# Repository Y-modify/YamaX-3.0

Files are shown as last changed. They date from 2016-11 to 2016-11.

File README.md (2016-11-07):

# YamaX 3.0

This is the software of humanoid robot named "YamaX 3.0"
The humanoid uses the original board with ESP8266.
This repository contains 3D Models, EAGLE files, and Arduino sketch.

Detailed information about this robot can be found in the following page: 

- [Y-modify](http://www.y-modify.org)
- [Y-modify Blog](http://blog.y-modify.org)

## Directory Structure

```
.
├── Designs
│   ├── AXBoard
│   │   ├── AX-03r	#EAGLE PCB file
│   │   └── Legacy	#Legacy Board (AX-03)
│   └── Model	#3D model of YamaX
├── Docs	#Document about the history of YamaX
└── Firmware
    └── AXBoard
        ├── AXTester	#Testing Program
        └── MCore	#Main Program
```

## Licence

These files are released under MIT Licence.
Please see `LICENCE`.

## Contact

You can comment on [our blog](http://blog.y-modify.org), or send e-mail to [info@y-modify.org](mailto:info@y-modify.org).

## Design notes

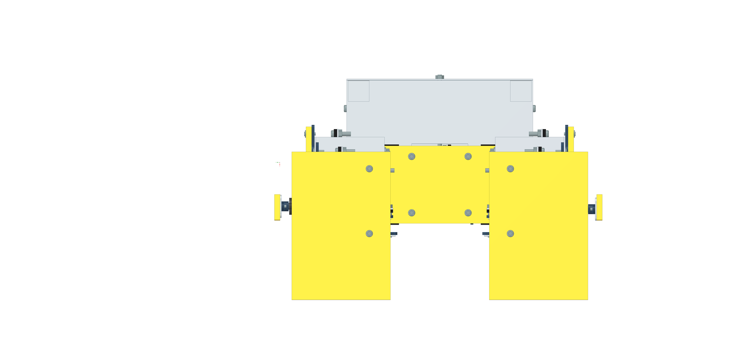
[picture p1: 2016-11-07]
Designs/Model/picts/解像度低め/YamaX3.0_redesigned_下.png

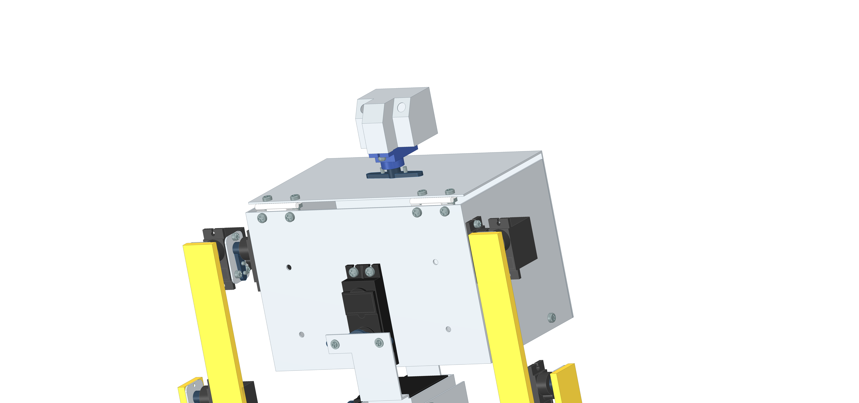
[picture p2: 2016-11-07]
Designs/Model/picts/YamaX3.0_redesigned_上半身.png

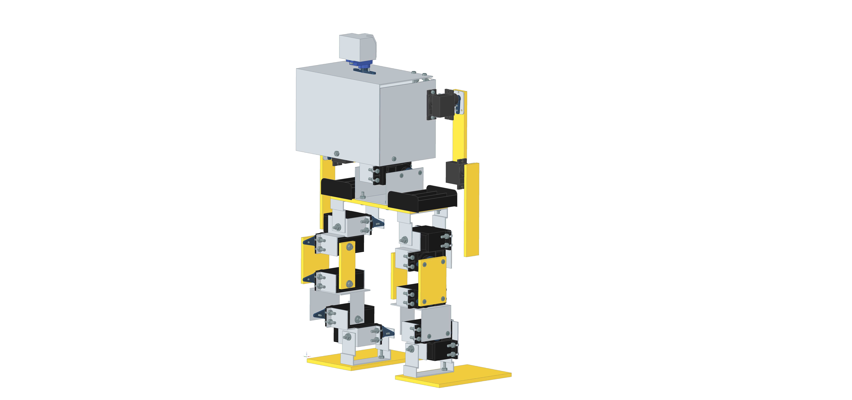
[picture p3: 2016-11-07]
Designs/Model/picts/YamaX3.0_redesigned_右後ろ.png

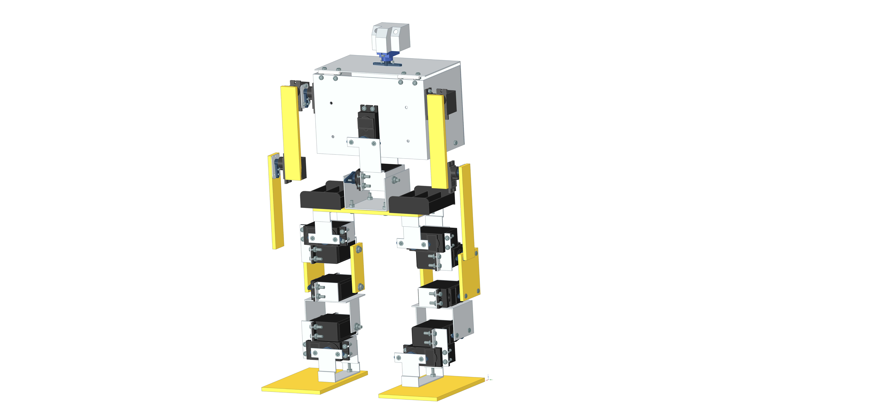
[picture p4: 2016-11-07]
Designs/Model/picts/YamaX3.0_redesigned_左前.png

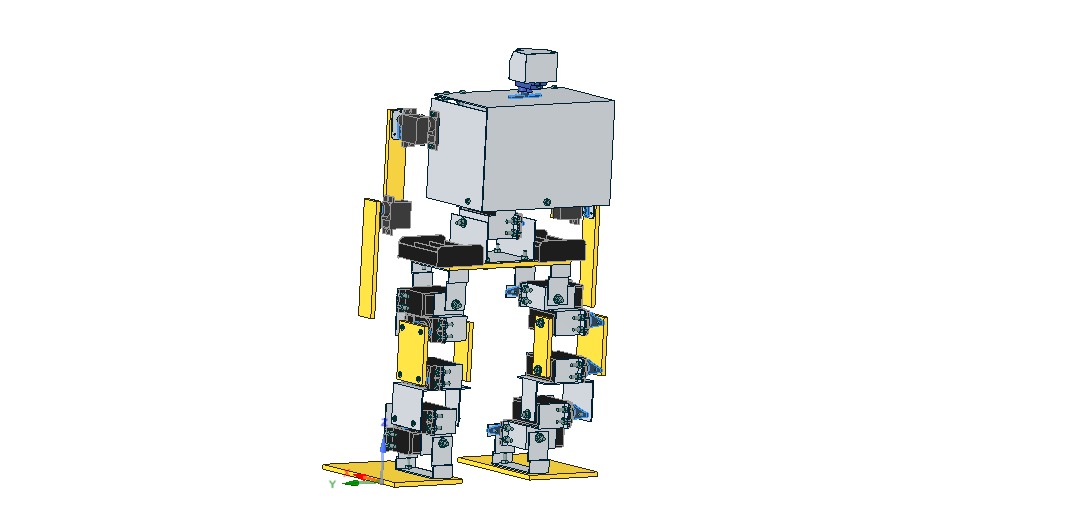
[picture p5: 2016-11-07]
Designs/Model/picts/解像度低め/5000/YamaX3.0_redesigned_左後ろ.jpg

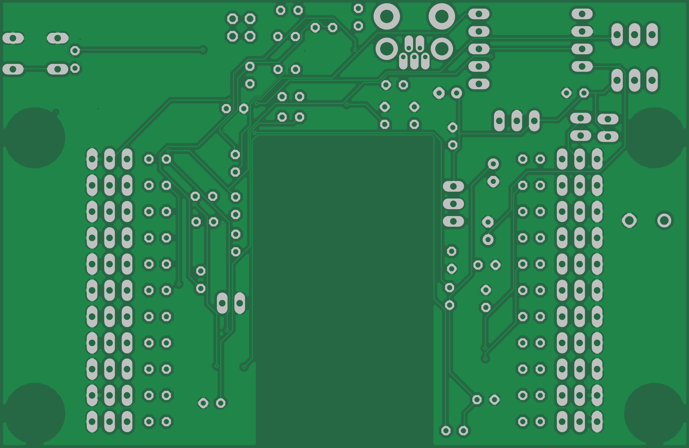
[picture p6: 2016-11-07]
Designs/AXBoard/AX-03r/Models/pcb/eagleUp_AX-03r_bottom_board.png

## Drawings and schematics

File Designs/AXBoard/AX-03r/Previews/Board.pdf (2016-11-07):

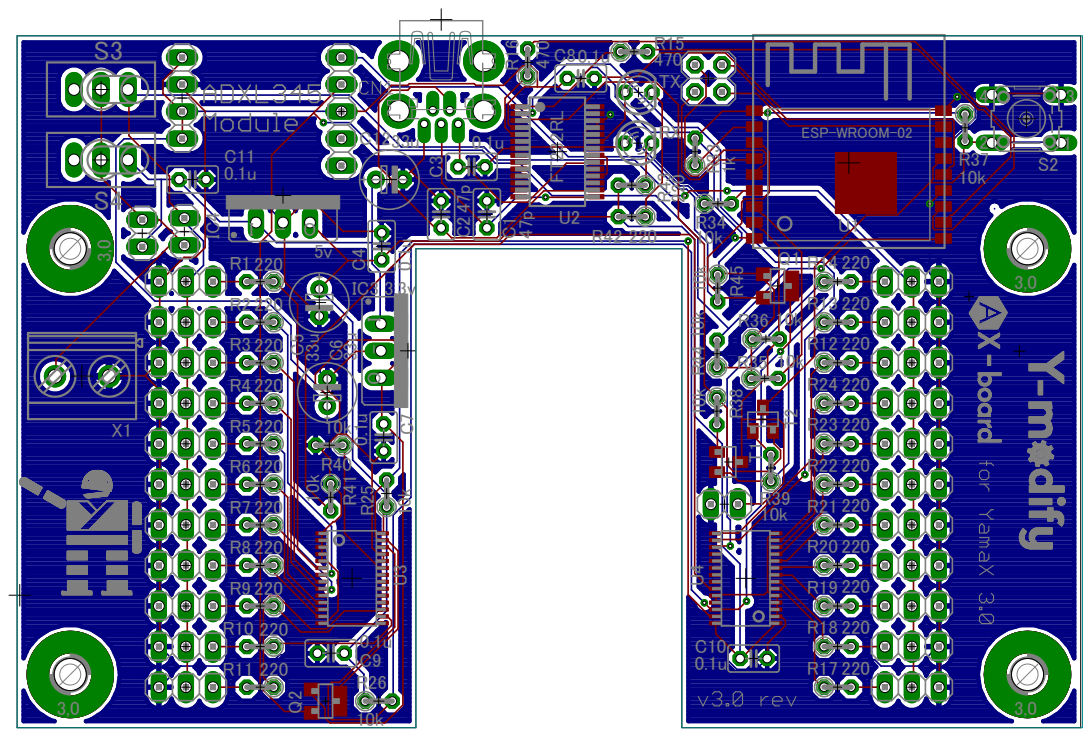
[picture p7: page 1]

- I O 2 1 4 3 I - O C1C2 C3 C4 C5 C6 C7 U1 U2 IC3 R1 R10 R11 R12 R13 R14 R17 R18 R19 R2 R20 R21 R22 R3 R33 R34 R35 R36 R37 R38 R39 R4 R40 R41 R42 R43 R44 R45 R5R6R7R8R9 RX S2 S3S4 T1 T2 TX U3U4 X1 R23 R24 R15 R16 C8 C9 C10 C11 C12 IC4 Q1 Q2 R25 R26 47p47p 0.1u 0.1u 33u 33u 0.1u ESP-WROOM-02 FT232RL 3.3v 220 220 220 220 220 220 220 220 220 220 220 220 220 220 1k 10k 10k 10k 10k 10k 10k 220 10k 10k 220 220 10k 10k 220 220 220 220 220 220 220 4470 70 0.1u 0.1u 0.1u 0.1u 33u 5v 10k 10k 3,0 3,0 3,0 3,0

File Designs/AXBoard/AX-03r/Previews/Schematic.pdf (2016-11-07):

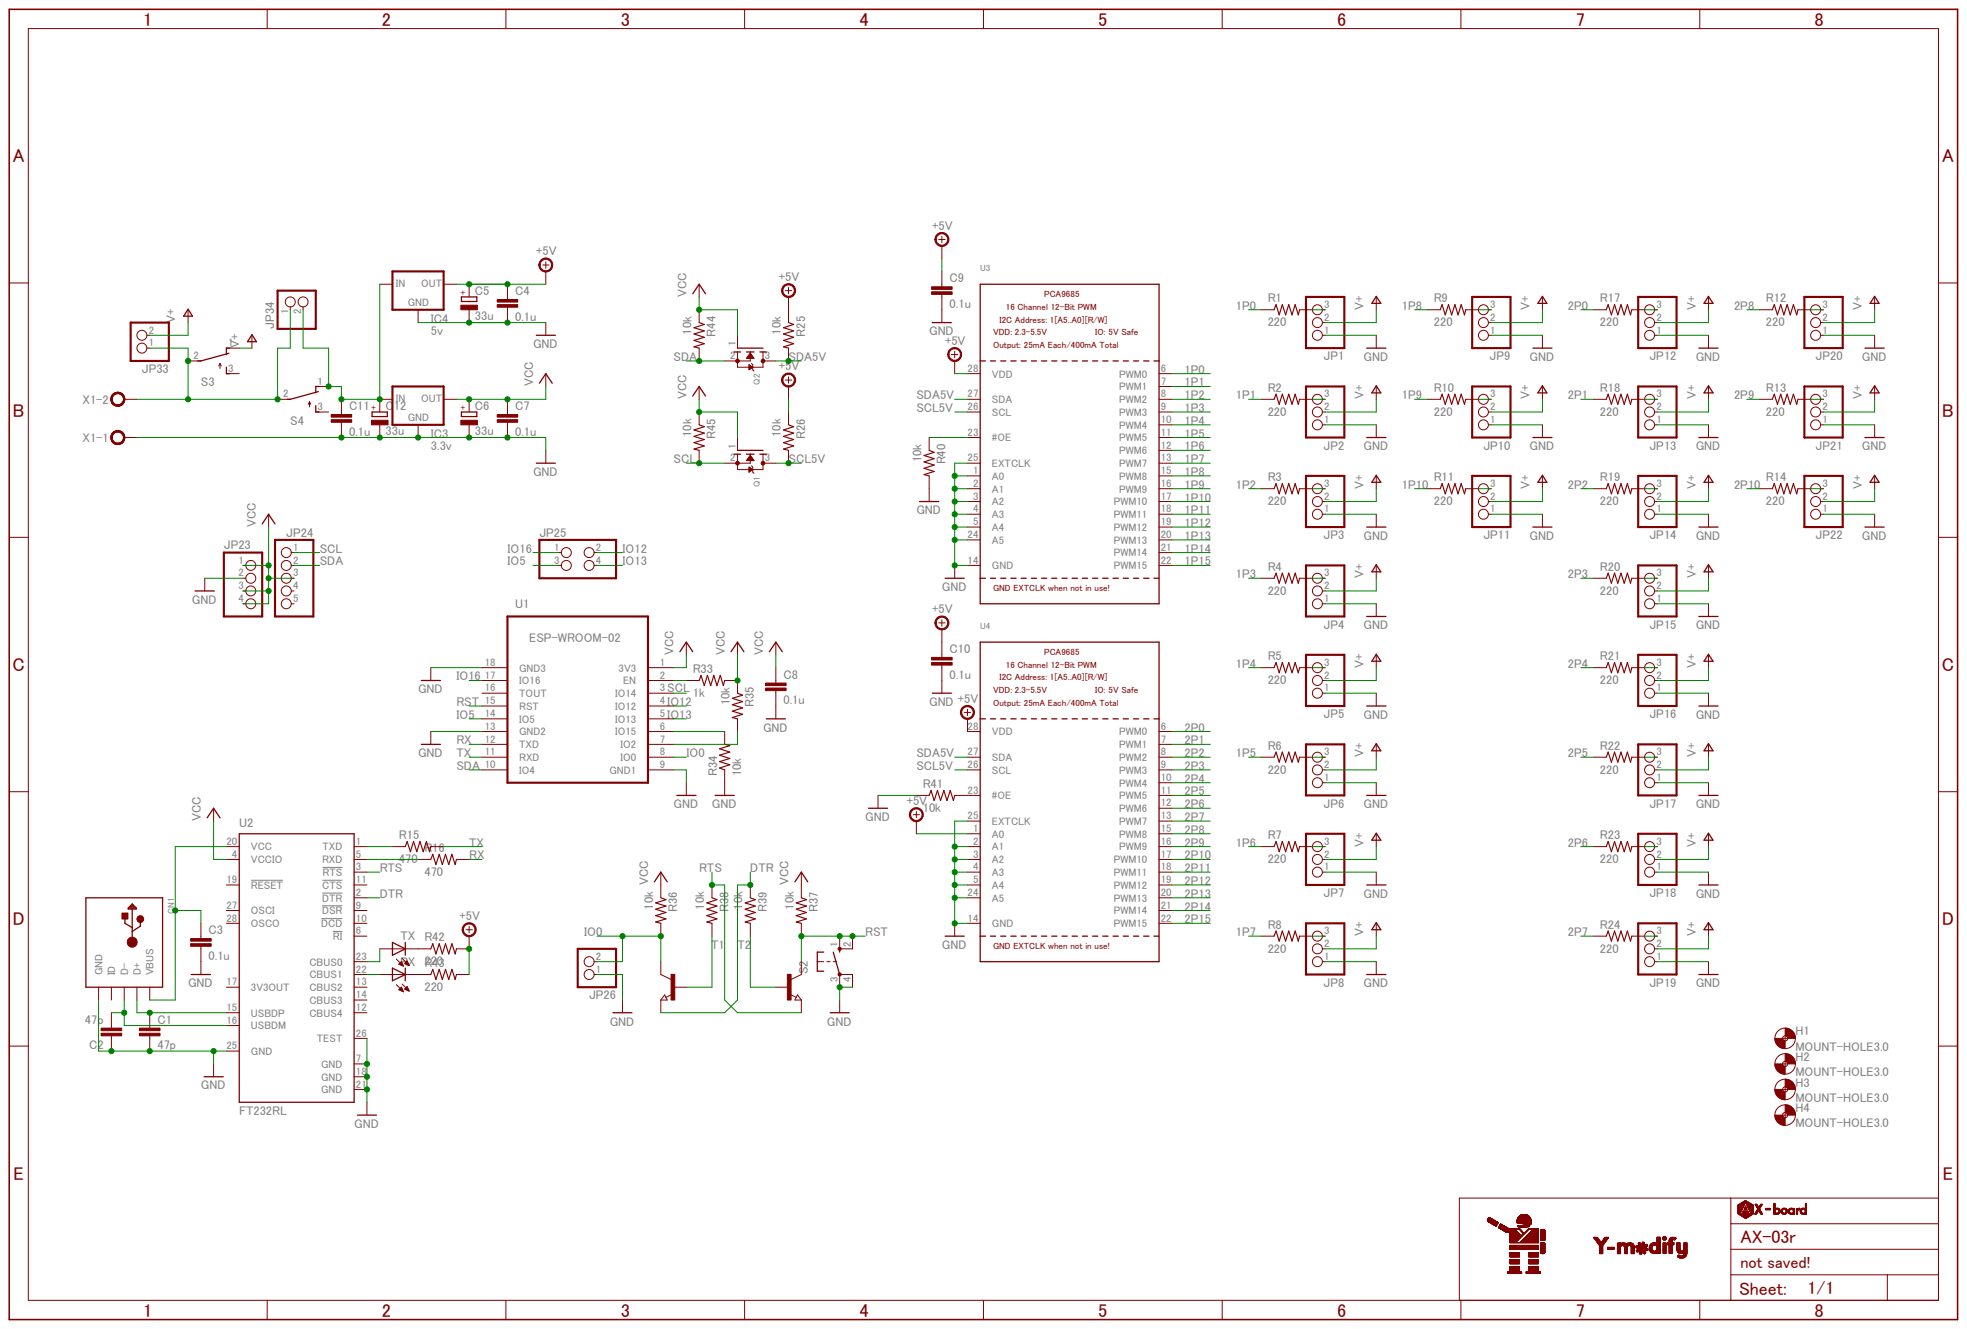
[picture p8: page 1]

GND EXTCLK when not in use!

MOUNT-HOLE3.0 MOUNT-HOLE3.0

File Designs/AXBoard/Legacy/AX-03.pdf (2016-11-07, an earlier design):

A

A

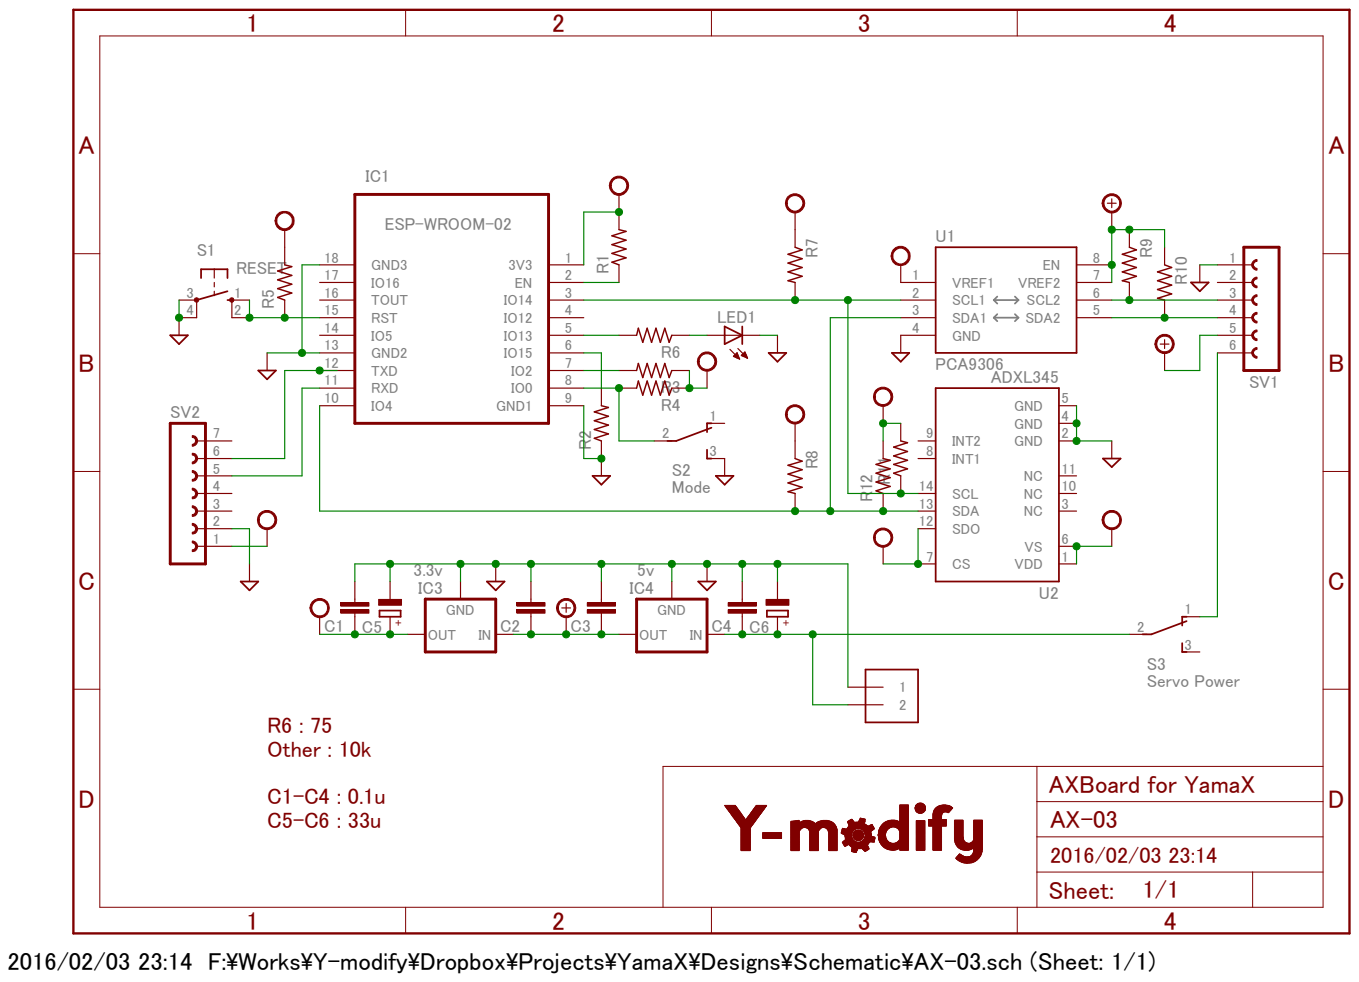
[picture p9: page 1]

2016/02/03 23:14 F:\Works\Y-modify\Dropbox\Projects\YamaX\Designs\Schematic\AX-03.sch (Sheet: 1/1)

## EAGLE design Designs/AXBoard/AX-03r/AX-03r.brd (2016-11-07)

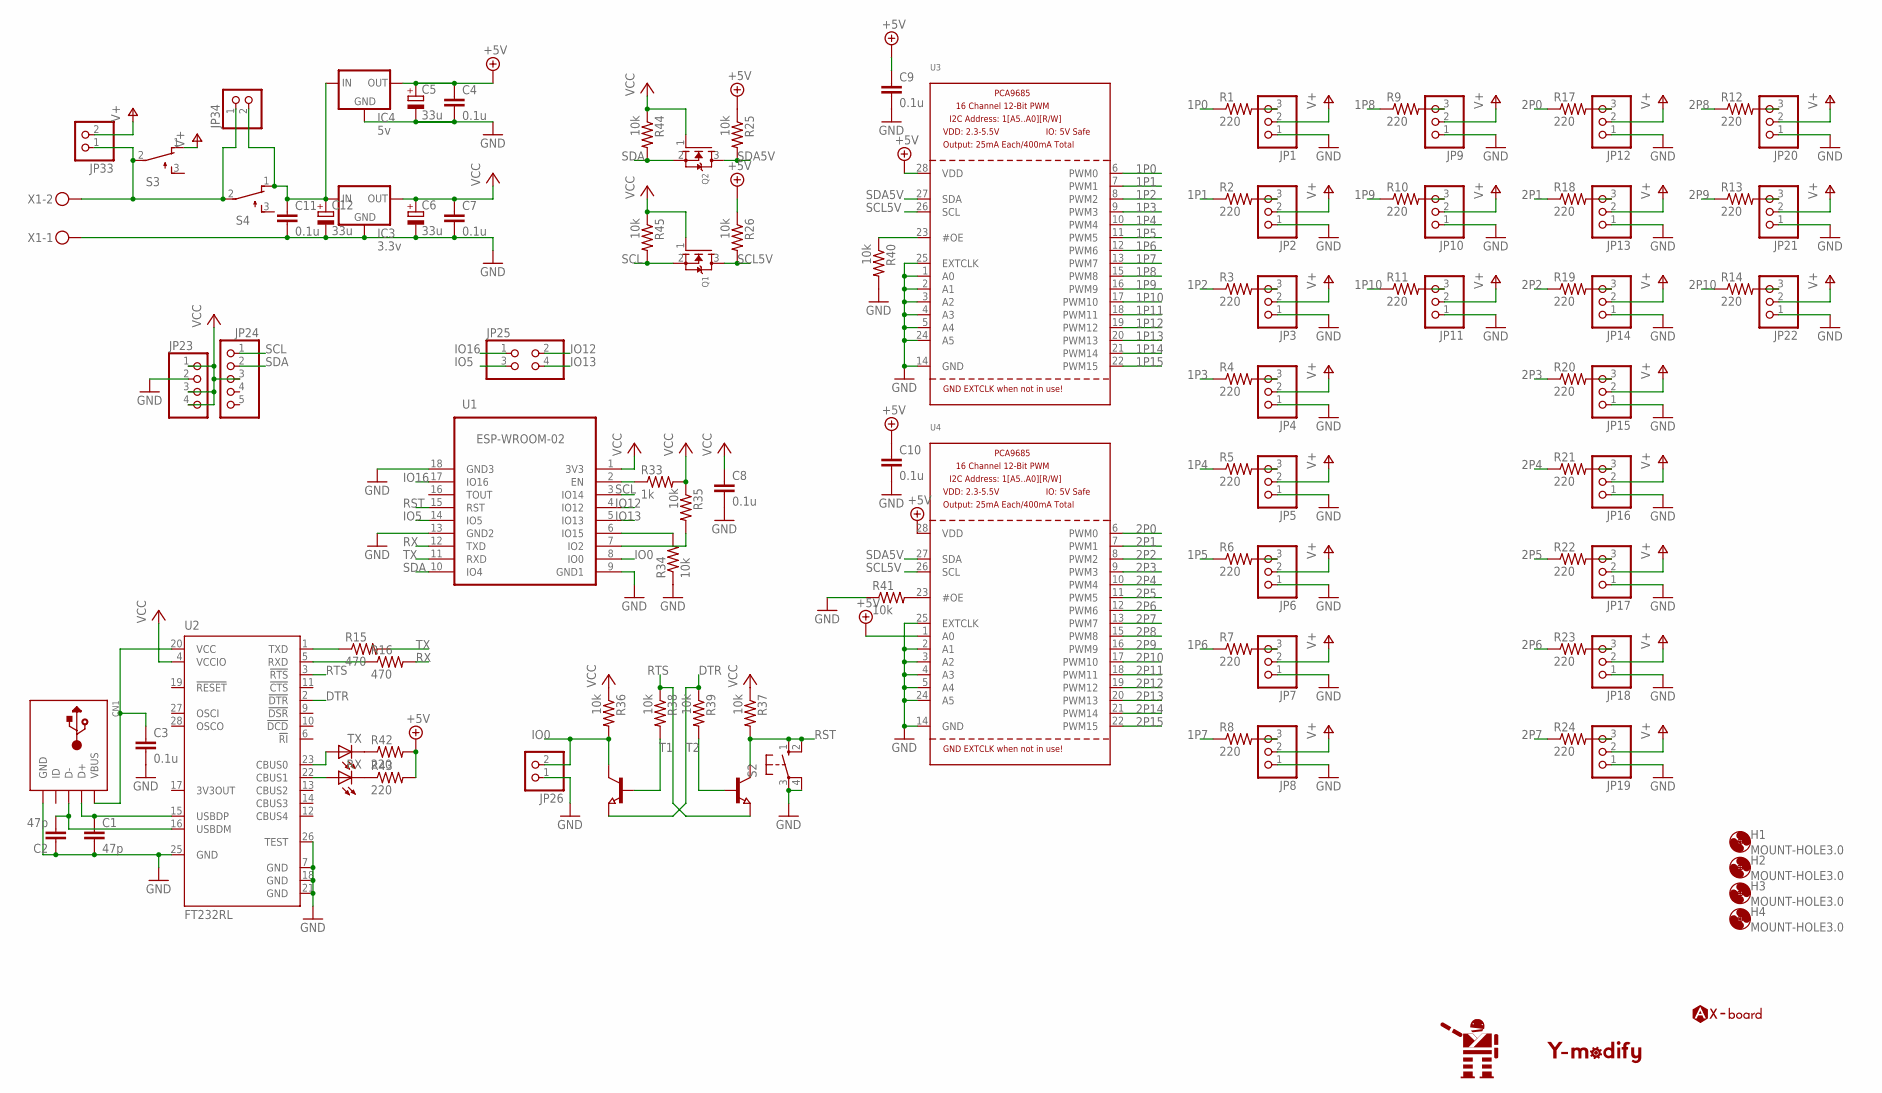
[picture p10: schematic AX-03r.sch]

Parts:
C1, C2: 47p; C025-025X050
C3, C4, C7, C8, C9, C10, C11: 0.1u; C025-025X050
C5, C6, C12: 33u; E2,5-6E
CN1: USBTHM; USB-MINIB-THM
H1, H2, H3, H4: MOUNT-HOLE3.0; 3,0
IC3: 3.3v; 78XXS
IC4: 5v; 78XXS
JP1, JP2, JP3, JP4, JP5, JP6, JP7, JP8, JP9, JP10, JP11, JP12, JP13, JP14, JP15, JP16, JP17, JP18, JP19, JP20, JP21, JP22: PINHD-1X3; 1X03
JP23: PINHD-1X4; 1X04
JP24: PINHD-1X5; 1X05
JP25: PINHD-2X2; 2X02
JP26, JP33, JP34: PINHD-1X2; 1X02
M1: MON
M2: Y-MODIFY
M3: AXBOARD
Q1, Q2: MOSFET-NWAVE; SOT23-W
R1, R2, R3, R4, R5, R6, R7, R8, R9, R10, R11, R12, R13, R14, R17, R18, R19, R20, R21, R22, R23, R24, R42, R43: 220; 0204V
R15, R16: 470; 0204V
R25, R26, R34, R35, R36, R37, R38, R39, R40, R41, R44, R45: 10k; 0204V
R33: 1k; 0204V
RX: LED3MM
S2: 10-XX; B3F-10XX
S3, S4: TL32PO; TL3XPO
T1, T2: NPN-TRANSISTOR_SOT23; SOT23
TX: LED3MM
U1: ESP-WROOM-02; FRONT-FACE
U2: FT232RL; SSOP28
U3, U4: PCA9685; TSSOP28
X1: MKDSN1,5/2-5,08

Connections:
1P0: R1.1, U3.6 (PWM0)
1P1: R2.1, U3.7 (PWM1)
1P2: R3.1, U3.8 (PWM2)
1P3: R4.1, U3.9 (PWM3)
1P4: R5.1, U3.10 (PWM4)
1P5: R6.1, U3.11 (PWM5)
1P6: R7.1, U3.12 (PWM6)
1P7: R8.1, U3.13 (PWM7)
1P8: R9.1, U3.15 (PWM8)
1P9: R10.1, U3.16 (PWM9)
1P10: R11.1, U3.17 (PWM10)
1P11: U3.18 (PWM11)
1P12: U3.19 (PWM12)
1P13: U3.20 (PWM13)
1P14: U3.21 (PWM14)
1P15: U3.22 (PWM15)
2P0: R17.1, U4.6 (PWM0)
2P1: R18.1, U4.7 (PWM1)
2P2: R19.1, U4.8 (PWM2)
2P3: R20.1, U4.9 (PWM3)
2P4: R21.1, U4.10 (PWM4)
2P5: R22.1, U4.11 (PWM5)
2P6: R23.1, U4.12 (PWM6)
2P7: R24.1, U4.13 (PWM7)
2P8: R12.1, U4.15 (PWM8)
2P9: R13.1, U4.16 (PWM9)
2P10: R14.1, U4.17 (PWM10)
2P11: U4.18 (PWM11)
2P12: U4.19 (PWM12)
2P13: U4.20 (PWM13)
2P14: U4.21 (PWM14)
2P15: U4.22 (PWM15)
+5V: C4.1, C5.+, C9.1, C10.1, IC4.OUT, R25.1, R26.1, R42.2, R43.2, U3.28 (VDD), U4.1 (A0), U4.28 (VDD)
DTR: R39.1, T1.2 (E), U2.2 (!DTR)
GND: C1.2, C2.1, C3.2, C4.2, C5.-, C6.-, C7.2, C8.2, C9.2, C10.2, C11.2, C12.-, CN1.GND, IC3.GND, IC4.GND, JP1.1, JP2.1, JP3.1, JP4.1, JP5.1, JP6.1, JP7.1, JP8.1, JP9.1, JP10.1, JP11.1, JP12.1, JP13.1, JP14.1, JP15.1, JP16.1, JP17.1, JP18.1, JP19.1, JP20.1, JP21.1, JP22.1, JP23.2, JP26.1, R34.1, R40.2, R41.1, S2.3, S2.4 (P1), U1.9 (GND1), U1.13 (GND2), U1.18 (GND3), U2.7 (GND), U2.18 (GND), U2.21 (GND), U2.25 (GND), U2.26 (TEST), U3.1 (A0), U3.2 (A1), U3.3 (A2), U3.4 (A3), U3.5 (A4), U3.14 (GND), U3.24 (A5), U3.25 (EXTCLK), U4.2 (A1), U4.3 (A2), U4.4 (A3), U4.5 (A4), U4.14 (GND), U4.24 (A5), U4.25 (EXTCLK), X1.1
IO0: JP26.2, R36.2, T1.3 (C), U1.8 (IO0)
IO5: JP25.3, U1.14 (IO5)
IO12: JP25.2, U1.4 (IO12)
IO13: JP25.4, U1.5 (IO13)
IO16: JP25.1, U1.17 (IO16)
unnamed: JP1.3, R1.2
unnamed: R33.1, U1.2 (EN)
unnamed: JP2.3, R2.2
unnamed: R34.2, U1.6 (IO15)
unnamed: JP3.3, R3.2
unnamed: R35.2, U1.7 (IO2)
unnamed: JP4.3, R4.2
unnamed: R41.2, U4.23 (#OE)
unnamed: JP5.3, R5.2
unnamed: R40.1, U3.23 (#OE)
unnamed: JP6.3, R6.2
unnamed: R38.2, T1.1 (B)
unnamed: JP7.3, R7.2
unnamed: R39.2, T2.1 (B)
unnamed: JP8.3, R8.2
unnamed: C1.1, CN1.D+, U2.15 (USBDP)
unnamed: JP9.3, R9.2
unnamed: JP10.3, R10.2
unnamed: JP11.3, R11.2
unnamed: JP20.3, R12.2
unnamed: JP21.3, R13.2
unnamed: JP22.3, R14.2
unnamed: C2.2, CN1.D-, U2.16 (USBDM)
unnamed: JP12.3, R17.2
unnamed: JP13.3, R18.2
unnamed: JP14.3, R19.2
unnamed: JP15.3, R20.2
unnamed: JP16.3, R21.2
unnamed: JP17.3, R22.2
unnamed: JP18.3, R23.2
unnamed: JP19.3, R24.2
unnamed: C3.1, CN1.VBUS, U2.20 (VCC)
unnamed: R42.1, TX.K (C)
unnamed: R43.1, RX.K (C)
unnamed: TX.A, U2.23 (CBUS0)
unnamed: RX.A, U2.22 (CBUS1)
unnamed: JP33.1, JP34.1, S3.2, S4.2, X1.2
unnamed: C11.1, C12.+, IC3.IN, IC4.IN, JP34.2, S4.1 (O)
unnamed: R15.1, U2.1 (TXD)
unnamed: R16.1, U2.5 (RXD)
RST: R37.2, S2.1 (S), S2.2 (S1), T2.3 (C), U1.15 (RST)
RTS: R38.1, T2.2 (E), U2.3 (!RTS)
RX: R16.2, U1.12 (TXD)
SCL: JP24.1, Q1.2 (S), R45.2, U1.3 (IO14)
SCL5V: Q1.3 (D), R26.2, U3.26 (SCL), U4.26 (SCL)
SDA: JP24.2, Q2.2 (S), R44.2, U1.10 (IO4)
SDA5V: Q2.3 (D), R25.2, U3.27 (SDA), U4.27 (SDA)
TX: R15.2, U1.11 (RXD)
V+: JP1.2, JP2.2, JP3.2, JP4.2, JP5.2, JP6.2, JP7.2, JP8.2, JP9.2, JP10.2, JP11.2, JP12.2, JP13.2, JP14.2, JP15.2, JP16.2, JP17.2, JP18.2, JP19.2, JP20.2, JP21.2, JP22.2, JP33.2, S3.1 (O)
VCC: C6.+, C7.1, C8.1, IC3.OUT, JP23.1, JP23.3, JP23.4, JP24.3, Q1.1 (G), Q2.1 (G), R33.2, R35.1, R36.1, R37.1, R44.1, R45.1, U1.1 (3V3), U2.4 (VCCIO)

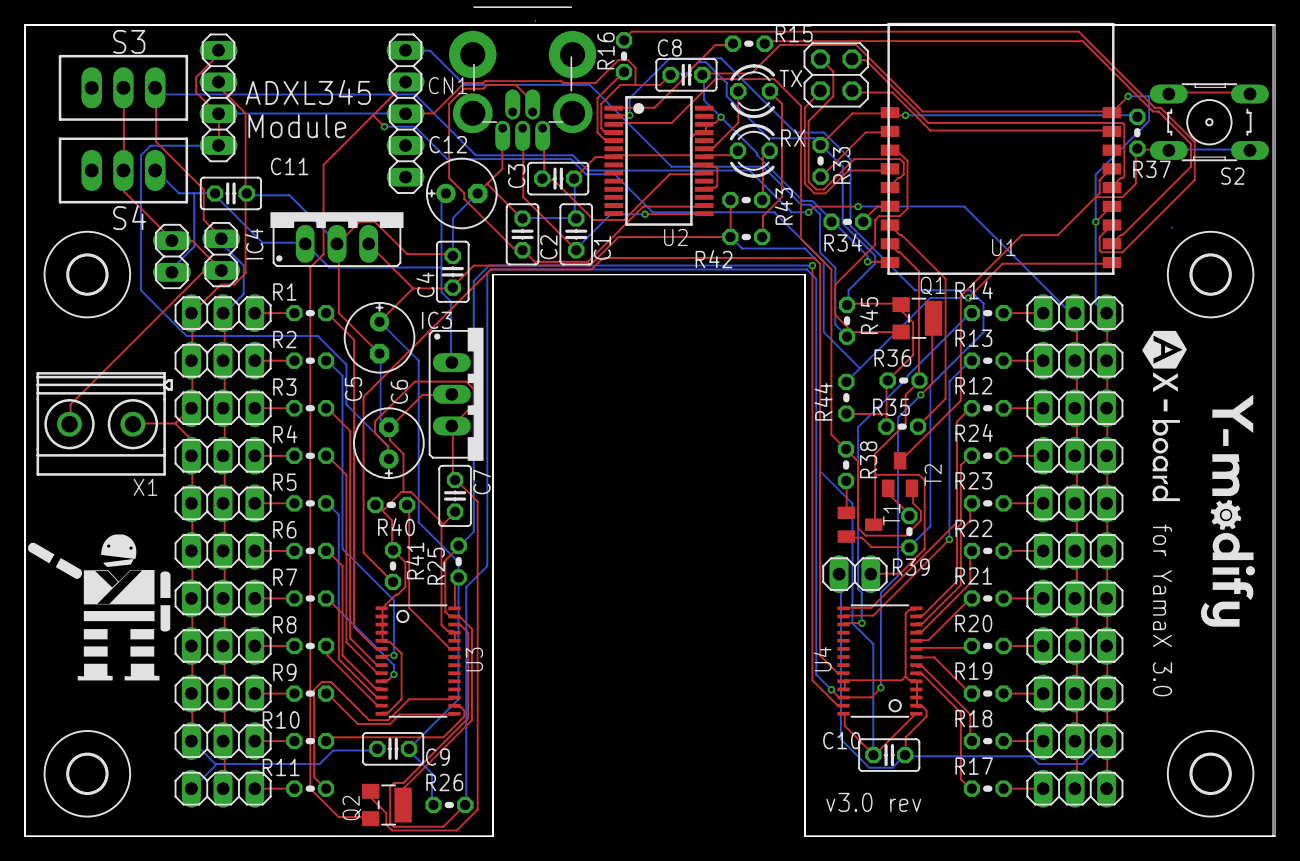
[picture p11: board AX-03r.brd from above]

Board: 2 copper layers, 100.2 x 65.0 mm, 103 parts (0 on the bottom side), 80 nets.

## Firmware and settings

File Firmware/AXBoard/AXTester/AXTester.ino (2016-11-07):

/*************************************
* AX-Board Testing Program
* To burn on AX-03 for YamaX 3.0
* made by Y-modify, coord.e
* Copyright © 2016 Y-modify All Rights Reserved.
* QIO,80,160,4M(1M),Disabled,none,nodemcu,115200~
*************************************/

#include <Wire.h>
#include <Adafruit_PWMServoDriver.h>
#include <Adafruit_Sensor.h>
#include <Adafruit_ADXL345_U.h>
#include <SerialCommand.h>

#define SERVOMIN  150
#define SERVOMAX  600

Adafruit_ADXL345_Unified accel = Adafruit_ADXL345_Unified(12345);

Adafruit_PWMServoDriver pwm1 = Adafruit_PWMServoDriver(0x40);
Adafruit_PWMServoDriver pwm2 = Adafruit_PWMServoDriver(0x41);

SerialCommand SCmd;

boolean output = true;
uint8_t lastDeg = 0;
uint8_t port = 0;
uint8_t type = 1; //0=x,1=y,2=z

uint8_t setServoPulse(uint8_t n, uint8_t degress) {
  if (degress > 180)
    return false;
  double pulse = map(degress, 0, 180, SERVOMIN, SERVOMAX);

  if (n < 16) {
    pwm1.setPWM(n, 0, pulse);
  }
  else if (n < 32) {
    pwm2.setPWM(n - 16, 0, pulse);
  }
  else {
    return false;
  }
  return pulse;
}

void changePort()
{
  Serial.print("port ");
  char *arg = SCmd.next();
  if (arg != NULL) {
    port = atoi(arg);
    Serial.println(port);
  }
  else {
    Serial.println("Enter the port.");
  }
  Serial.print("~$ ");
}

void setDeg()
{
  Serial.print("deg ");
  char *arg = SCmd.next();
  if (arg != NULL) {
    int val = atoi(arg);
    Serial.println(val);
    output = false;
    setServoPulse(port, val);
  }
  else {
    Serial.println("Enter the value.");
  }
  Serial.print("~$ ");
}

void setType()
{
  Serial.print("type ");
  char *arg = SCmd.next();
  if (arg != NULL) {
    Serial.println(arg);
    if(strcmp("x",arg) == 0){
      type = 0;
    }else if(strcmp("y",arg) == 0){
      type = 1;
    }else if(strcmp("z",arg) == 0){
      type = 2;      
    }else{
      Serial.println("Please enter x, y, or z.");
    }
  }
  else {
    Serial.println("\nEnter enter x, y, or z.");
  }
  Serial.print("~$ ");
}

void printHelp()
{
  Serial.println("help");
  Serial.println("\n************************");
  Serial.println("Tester for AXBoard");
  Serial.println("Shell-like board testing program");
  Serial.println("Commands:");
  Serial.println("- \"port *\": change output servo's port");
  Serial.println("- \"type [x,y,z]\": set output accel type");
  Serial.println("- \"stop\": stop syncing with accel");
  Serial.println("- \"start\": start syncing with accel");
  Serial.println("- \"deg *\": change servo's degress and stop syncing with accel");
  Serial.println("- \"watch (-i)\": show values");
  Serial.println("- \"help\": show this information again");
  Serial.println("************************\n");
  Serial.print("~$ ");
}

void setup() {
  Serial.begin(9600);
  Serial.print("\n~$ ");
  printHelp();

  delay(200);
    
  if(!accel.begin())
  {
    Serial.println("Error: no ADXL345 detected ... Check your wiring!");
    Serial.println("Exit.");
    while(1){ delay(10); }
  }

  accel.setRange(ADXL345_RANGE_16_G);
  
  pwm1.begin();
  pwm2.begin();
  
  pwm1.setPWMFreq(60);
  pwm2.setPWMFreq(60);

  SCmd.addCommand("port", changePort);
  SCmd.addCommand("watch", [](){
    Serial.print("watch ");
    char *arg = SCmd.next();
    if (arg != NULL) {
      Serial.println(arg);
      if(strcmp("-i", arg) == 0){
        Serial.println("X\tY\tZ");
        while(1){
          Serial.print(accel.getX());Serial.print("\t");
          Serial.print(accel.getY());Serial.print("\t");
          Serial.print(accel.getZ());Serial.print("\n");
          delay(100);
        }
      }else{
        Serial.println("Unrecognized option");
      }
    }else{
      Serial.print("\nX: ");Serial.println(accel.getX());
      Serial.print("Y: ");Serial.println(accel.getY());
      Serial.print("Z: ");Serial.println(accel.getZ());
      Serial.print("Port: ");Serial.println(port);
      Serial.print("Degress: ");Serial.println(lastDeg);
    }
    Serial.print("~$ ");
  });
  SCmd.addCommand("stop", [](){ 
    Serial.println("stop");
    output = false; 
    Serial.println("stopped");
    Serial.print("~$ ");
  });
  SCmd.addCommand("start", [](){ 
    Serial.println("start");
    output = true; 
    Serial.println("started");
    Serial.print("~$ ");
  });
  SCmd.addCommand("type", setType);
  SCmd.addCommand("deg", setDeg);
  SCmd.addCommand("help", printHelp);
  SCmd.setDefaultHandler([](const char *command){ 
    Serial.println(command);
    Serial.print(command); 
    Serial.println(": command not found"); 
    Serial.print("~$ ");
  });
}

void loop() {
  if(output){
    int value;
    switch(type){
      case 0:
      value = accel.getX();
      break;
      case 1:
      value = accel.getY();
      break;
      case 2:
      value = accel.getZ();
      break;
      default:break;
    }
    lastDeg = map(value, -275, 275, 0, 180);
    setServoPulse(port, lastDeg);
  }
  SCmd.readSerial();
  delay(30);
}

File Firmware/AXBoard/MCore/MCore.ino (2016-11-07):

/*************************************
  YamaX Arduino Core v3.0
  To burn on AX-03 for YamaX 3.0
  made by Y-modify, Nyanyan & coord.e
  Copyright © 2016 Y-modify All Rights Reserved.
  QIO,80,160,4M(1M),Disabled,none,nodemcu,115200~
*************************************/

/*****Version Definition*****/
#define YAMAX_VER "3.0"
#define FIRMWARE_VER "3.0"

#if defined(ARDUINO_ESP8266_ESP01)  //AX-03
#define S_WIFI    //Support Wifi         comment out to wifi free
//#define S_REMOTE  //Support Remote       comment out to wifi free*
#define S_SERVER  //Support Server       comment out to wifi free
//#define S_OTA     //Support OTA Update   comment out to wifi free*
#define S_ACCEL     //Support Accelerometer
#define BOARD_VER "03"
#elif defined(ARDUINO_AVR_UNO)  //AX-01
#define S_STABLE
#define BOARD_VER "01"
#else
#error This board is not supported! Please use ESP8266 or Arduino UNO.
#endif

#include <libcolor.h>
colors color(THEME_PRIMARY);

#define LED 13

/*****Web Console*****/
String console;
String motion;
bool encout = true;

/*****System Setup*****/
void setup() {
  Serial.begin(115200);
  delay(1000);

  print_c("HELLO YamaX %s\n", YAMAX_VER);

  verInfo();  //Print Version Information

  print_c("Initializing...\n");

  ControlInit();  //Serial Command Control Initialize

  ServoInit();  //Servo Driver Setup

  setLEDColor(color.RED());
  stand();

#if defined(S_WIFI)
  NetInit();  //Connect to Wifi
#endif
#if defined(S_SERVER)
  ServerInit(); //Initialize Server
#endif
#if defined(S_OTA)
  OTAInit();  //Initialize OTA Updater
#endif

  //Start
  setLEDColor(color.GREEN());

  print_c("Initialization Complete.\n");

  /*   for(int i = 0; i <5; i++)
     {
       stand();
       delay(5000);
      bow();
       delay(900);
       stand();
       delay(2000);
       walk(10,300);
       stand();
       delay(1000);
      bye(10);
       stand();
       delay(1000);
       no(5);
     }*/
  //  delay(4000);
  //  walk(10,300);
  //  stand();
  // kusoran();
}

/*****Waiting Loop*****/
void loop() {
  CommandCheck();
#if defined(S_OTA)
  OTACheck();
#endif
#if defined(S_SERVER)
  ServerCheck();
#endif
#if defined(S_REMOTE)
  RemoteCheck();
#endif
#if defined(S_REMOTE) || defined(S_SERVER)
  if (!motion.compareTo("stand")) {
    stand();
    encout = true;
  } else {
    encout = false;
    if (!motion.compareTo("straight")) { //in case of straight
      walk(1, 170);
    } else if (!motion.compareTo("right")) {
      turnright(1, 170);
    } else if (!motion.compareTo("left")) {
      turnleft(1, 170);
    } else if (!motion.compareTo("bow")) {
      bow(0);
    } else if (!motion.compareTo("bye")) {
      bye(1);
    } else if (!motion.compareTo("no")) {
      no(1);
    }
  }
#endif
  //doAccelProcess();
  delay(1);
}

/*****Print Version Information*****/
void verInfo() {
  print_c("\n*************************************\n");
  print_c("YamaX Arduino Core (MCore) v%s\n", FIRMWARE_VER);
  print_c("To burn on AX-%s for YamaX %s\n", BOARD_VER, YAMAX_VER);
  print_c("Made by Y-modify, Nyanyan & coord.e\n");
  print_c("Copyright (c) 2016 Y-modify All Rights Reserved.\n");
  print_c("*************************************\n\n");
}

/*****That's all. Enjoy!*****/

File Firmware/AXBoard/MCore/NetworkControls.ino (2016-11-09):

/*************************************
  Networks - YamaX Arduino Core v3.0
  Networking block
  made by coord.e, Y-modify
  Copyright © 2016 Y-modify All Rights Reserved.
*************************************/

#if defined(S_WIFI)  //Only Wifi Support

#include <ESP8266WiFi.h>
#include <ESP8266mDNS.h>
#include <WiFiUdp.h>
#include <ArduinoOTA.h>
#include <WiFiClient.h>
#include <ESP8266WebServer.h>
#include <EEPROM.h>
#include <ESP8266HTTPClient.h>

/*****Wifi Settings*****/
#define ESPHOST "yamax-ota"
#define ESPSERVER "yamax"
#define ESPSETADDR 0

#define COMURL "http://debug.y-modify.org/axboard-remote/command.txt"
#define CTRLURL "http://debug.y-modify.org/axboard-remote/control.html"
#define CONURL "http://debug.y-modify.org/axboard-remote/console.html"

struct WiFiConfig {
  char ssid[32];
  char pass[32];
};

/*****Object Making*****/
ESP8266WebServer server(80);

/*****Initialization for Wifi*****/
void NetInit() {
  EEPROM.begin(100);
  WiFiConfig buf;
  EEPROM.get<WiFiConfig>(ESPSETADDR, buf);
  WiFi.mode(WIFI_STA);
  WiFi.begin(buf.ssid, buf.pass);
  while (WiFi.waitForConnectResult() != WL_CONNECTED) {
    Serial.println("Connection Failed! Scanning other networks...");
    int n = WiFi.scanNetworks();
    Serial.println("Scan done");
    if (n == 0)
      Serial.println("No networks found. Continue with non-wifi enviromnent");
    else
    {
      Serial.print(n);
      Serial.println(" networks found");
      for (int i = 0; i < n; ++i)
      {
        // Print SSID and RSSI for each network found
        Serial.print(i + 1);
        Serial.print(": ");
        Serial.print(WiFi.SSID(i));
        Serial.print(" (");
        Serial.print(WiFi.RSSI(i));
        Serial.print(")");
        Serial.println((WiFi.encryptionType(i) == ENC_TYPE_NONE) ? " " : "*");
        delay(10);
      }
    }
    Serial.println("Enter the number: ");
    while (!Serial.available()) {
      delay(100);
    }
    int num = Serial.parseInt();
    Serial.print("Connect to "); Serial.println(WiFi.SSID(num - 1));
    Serial.println("Enter the password: ");
    while (Serial.available()) Serial.read(); //While data is available, read data (Clean buffer)
    while (!Serial.available()) {
      delay(100);
    }
    char buf[31];
    for (int j = 0; j < 30; j++) {
      buf[j] = Serial.read();
      if (buf[j] == '\n') {
        buf[j] = '\0';
        break;
      }
    }
    Serial.write(buf);
    Serial.write("\n");
    Serial.println("Trying to connect...");
    WiFi.begin(WiFi.SSID(num - 1).c_str(), buf);
    if (WiFi.waitForConnectResult() == WL_CONNECTED) {
      Serial.println("Done. Do you want to save this?(0/1)");
      while (Serial.available()) Serial.read(); //While data is available, read data (Clean buffer)
      while (!Serial.available()) {
        delay(100);
      }
      if (Serial.parseInt() == 1) {
        Serial.println("Saving...");
        char ssidbuf[30];
        strcpy(ssidbuf, WiFi.SSID(num - 1).c_str());
        ChangeWifiSetting(ssidbuf, buf);
      }
    } else {
      Serial.println("Oh no...");
    }
  }
  IPAddress ip = WiFi.localIP();
  String ipStr = String(ip[0]) + '.' + String(ip[1]) + '.' + String(ip[2]) + '.' + String(ip[3]);
  print_c("Wifi has initialized. IP is: %s\n", ipStr.c_str());
}
/*****Initialization for Web Server*****/
void ServerInit() {
  if (MDNS.begin(ESPSERVER)) {
    print_c("MDNS responder started\n");
  }
  server.on("/", []() {
    HTTPClient http;
    http.begin(CONURL);
    int httpCode = http.GET();
    server.send(httpCode, "text/html", http.getString());
    http.end();
  });
  server.on("/console", []() {
    digitalWrite(LED, HIGH);
    server.send(200, "text/plain", console);
    digitalWrite(LED, LOW);
  });
  server.on("/set", []() {
    if (server.hasArg("c")) {
      motion = server.arg("c");
      print_c("motion is set (%s)\n", motion.c_str());
      server.send(200, "text/plain", "done");
    } else
      server.send(404, "text/plain", "Please use c option to set motion");
  });
  server.on("/control", []() {
    HTTPClient http;
    http.begin(CTRLURL);
    int httpCode = http.GET();
    server.send(httpCode, "text/html", http.getString());
    http.end();
  });
  server.on("/do", []() {
    if (server.hasArg("c")) {
      processCommand(server.arg("c"));
      server.send(200, "text/plain", "done");
    } else
      server.send(404, "text/plain", "Please use c option to do motion");
  });
  server.onNotFound([]() {
    server.send(404, "text/plain", "Flie not found");
  });
  server.begin();
}

void processCommand(String doing) {
  if (!doing.compareTo("walk")) { //in case of straight
    walk(server.hasArg("arg1") ? server.arg("arg1").toInt() : 6, server.hasArg("arg2") ? server.arg("arg2").toInt() : 200);
    stand();
  } else if (!doing.compareTo("right")) {
    turnright(server.hasArg("arg1") ? server.arg("arg1").toInt() : 6, server.hasArg("arg2") ? server.arg("arg2").toInt() : 200);
    stand();
  } else if (!doing.compareTo("left")) {
    turnleft(server.hasArg("arg1") ? server.arg("arg1").toInt() : 6, server.hasArg("arg2") ? server.arg("arg2").toInt() : 200);
    stand();
  } else if (!doing.compareTo("bow")) {
    bow(server.hasArg("arg1") ? server.arg("arg1").toInt() : 800);
    stand();
  } else if (!doing.compareTo("bye")) {
    bye(server.hasArg("arg1") ? server.arg("arg1").toInt() : 4);
    stand();
  } else if (!doing.compareTo("no")) {
    no(server.hasArg("arg1") ? server.arg("arg1").toInt() : 4);
    stand();
  } else if (!doing.compareTo("dance")) {
    dance(server.hasArg("arg1") ? server.arg("arg1").toInt() : 4);
    stand();
  } else if (!doing.compareTo("stand")) {
    stand();
  } else if (!doing.compareTo("version")) {
    verInfo();
  } else if (!doing.compareTo("kusoran")) {
    kusoran();
    stand();
  } else if (!doing.compareTo("red")) {
    ledRed();
  } else if (!doing.compareTo("green")) {
    ledGreen();
  } else if (!doing.compareTo("blue")) {
    ledBlue();
  } else if (!doing.compareTo("setred")) {
    setLEDr(map(server.hasArg("arg1") ? server.arg("arg1").toInt() : 100, 0, 100, 0, LEDREDMAX));
  } else if (!doing.compareTo("setgreen")) {
    setLEDg(map(server.hasArg("arg1") ? server.arg("arg1").toInt() : 100, 0, 100, 0, LEDGREENMAX));
  } else if (!doing.compareTo("setblue")) {
    setLEDb(map(server.hasArg("arg1") ? server.arg("arg1").toInt() : 100, 0, 100, 0, LEDBLUEMAX));
  } else if (!doing.compareTo("setwifi")) {
    print_c("I can't configure Wifi through Wifi console.\nSorry!");
  } else {
    what(doing.c_str());
  }
}

void ChangeWifiSetting(char* wssid, char* wpass) {
  WiFiConfig buf;
  strcpy(buf.ssid, wssid);
  strcpy(buf.pass, wpass);
  EEPROM.put<WiFiConfig>(0, buf);
  EEPROM.commit();
}
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

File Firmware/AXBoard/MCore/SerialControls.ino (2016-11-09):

/*************************************
  Controls - YamaX Arduino Core v3.0
  Command control block
  made by coord.e, Y-modify
  Copyright © 2016 Y-modify All Rights Reserved.
*************************************/

#include <SerialCommand.h>

SerialCommand SCmd;

void ControlInit() {
  SCmd.addCommand("walk", walkStep);
  SCmd.addCommand("right", tRightStep);
  SCmd.addCommand("left", tLeftStep);
  SCmd.addCommand("bow", bowS);
  SCmd.addCommand("dance", danceS);
  SCmd.addCommand("stand", stand);
  SCmd.addCommand("bye", byeS);
  SCmd.addCommand("no", noS);
  SCmd.addCommand("kusoran", kusoran);
  SCmd.addCommand("red", ledRed);
  SCmd.addCommand("green", ledGreen);
  SCmd.addCommand("blue", ledBlue);
  SCmd.addCommand("yellow", ledYellow);
  SCmd.addCommand("white", ledWhite);
  SCmd.addCommand("setred", ledRedAdj);
  SCmd.addCommand("setgreen", ledGreenAdj);
  SCmd.addCommand("setblue", ledBlueAdj);
  SCmd.addCommand("version", verInfo);
  SCmd.addCommand("setwifi", setWifi);
  SCmd.setDefaultHandler(what);
}

void CommandCheck() {
  SCmd.readSerial();
}

/*****Functions for Response*****/
void walkStep() {
  char *arg;

  arg = SCmd.next();
  if (arg != NULL)
  {
    int steps = atoi(arg);    // Converts a char string to an integer
    arg = SCmd.next();
    if (arg != NULL)
    {
      int del = atol(arg);
      walk(steps, del);
    }
    else {
      what();
    }
  }
  else {
    what();
  }
  stand();
  clearBuf();
}

void bowS() {
  char *arg;

  arg = SCmd.next();
  if (arg != NULL)
  {
    int val = atoi(arg);
    bow(val);
  }
  else {
    what();
  }
  stand();
  clearBuf();
}

void noS() {
  char *arg;

  arg = SCmd.next();
  if (arg != NULL)
  {
    int val = atoi(arg);
    no(val);
  }
  else {
    what();
  }
  stand();
  clearBuf();
}

void danceS() {
  char *arg;

  arg = SCmd.next();
  if (arg != NULL)
  {
    int val = atoi(arg);
    dance(val);
  }
  else {
    what();
  }
  stand();
  clearBuf();
}

void byeS() {
  char *arg;

  arg = SCmd.next();
  if (arg != NULL)
  {
    int val = atoi(arg);
    bye(val);
  }
  else {
    what();
  }
  stand();
  clearBuf();
}

void tRightStep() {
  char *arg;

  arg = SCmd.next();
  if (arg != NULL)
  {
    int steps = atoi(arg);    // Converts a char string to an integer
    arg = SCmd.next();
    if (arg != NULL)
    {
      int del = atol(arg);
      turnright(steps, del);
    }
    else {
      what();
    }
  }
  else {
    what();
  }
  stand();
  clearBuf();
}

void tLeftStep() {
  char *arg;

  arg = SCmd.next();
  if (arg != NULL)
  {
    int steps = atoi(arg);    // Converts a char string to an integer
    arg = SCmd.next();
    if (arg != NULL)
    {
      int del = atol(arg);
      turnleft(steps, del);
    }
    else {
      what();
    }
  }
  else {
    what();
  }
  stand();
  clearBuf();
}

void ledRedAdj() {
  char *arg;

  arg = SCmd.next();
  if (arg != NULL)
  {
    int val = atoi(arg);    // Converts a char string to an integer
    print_c("Set red LED to %d\n", val);
    setLEDr(map(val, 0, 100, 0, LEDREDMAX));
  }
  else {
    what();
  }
  clearBuf();
}

void ledGreenAdj() {
  char *arg;

  arg = SCmd.next();
  if (arg != NULL)
  {
    int val = atoi(arg);    // Converts a char string to an integer
    print_c("Set green LED to %d\n", val);
    setLEDg(map(val, 0, 100, 0, LEDGREENMAX));
  }
  else {
    what();
  }
  clearBuf();
}

void ledBlueAdj() {
  char *arg;

  arg = SCmd.next();
  if (arg != NULL)
  {
    int val = atoi(arg);    // Converts a char string to an integer
    print_c("Set blue LED to %d\n", val);
    setLEDb(map(val, 0, 100, 0, LEDBLUEMAX));
  }
  else {
    what();
  }
  clearBuf();
}

void ledRed() {
  setLEDColor(color.RED());
}

void ledBlue() {
  setLEDColor(color.BLUE());
}

void ledGreen() {
  setLEDColor(color.GREEN());
}

void ledYellow() {
  setLEDColor(color.YELLOW());
}

void ledWhite() {
  setLEDColor(color.WHITE());
}

void setWifi() {
#if defined(S_WIFI)
  char *arg;

  arg = SCmd.next();
  if (arg != NULL)
  {
    char wssid[32];
    strcpy(wssid, arg);
    arg = SCmd.next();
    if (arg != NULL)
    {
      print_c("Change Wifi Settings\nSSID: %s\nPASS: %s\n", wssid, arg);
      ChangeWifiSetting(wssid, arg);
    }
    else {
      what();
    }
  }
  else {
    what();
  }
  stand();
#else
  print_c("This Feature is not Supported\n");
#endif
  clearBuf();
}

void what() {
  print_c("I can't understand.\n");
  no(2);
  stand();
}

void what(const char *command) {
  print_c("Command \"%s\" is not defined\n", command);
  no(2);
  stand();
}

void clearBuf() {
  while (Serial.available())
    Serial.read();
}

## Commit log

2016-11-07 Initial Commit of YamaX 3.0
    [AX-03.sch, AX-03r.brd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]
2016-11-09 Revert "Translated Japanese comments into English"
    This reverts commit a54f7284c32f948907b702977640837f4fbb292b.
    [Actions.ino, NetworkControls.ino, SerialControls.ino]
2016-11-09 Revert "Revert "Translated Japanese comments into English""
    This reverts commit 1ec2eaea017d5ec38816b4111e9fea511e947f91.
    [Actions.ino, NetworkControls.ino, SerialControls.ino]

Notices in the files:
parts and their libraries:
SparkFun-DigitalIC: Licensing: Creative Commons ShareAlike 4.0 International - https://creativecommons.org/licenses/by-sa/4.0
